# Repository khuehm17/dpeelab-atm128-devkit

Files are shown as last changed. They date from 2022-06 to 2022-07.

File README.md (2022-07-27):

# ATMEGA128 DEVELOPMENT KIT 
## Design by DPEE Lab
## #dpeelab-atm128-devkit
---
## Project description

An open-source AVR ATMega128 Development board KIT design with sample firmware

---
## Features
- 5V/3A Power supply
- ATMega128X compatibility
- USB Type C Serial UART
- JTAG/ISP Debug, programmer header
- Stackable with another module or extension board

---
## Hardware Revision 1.0

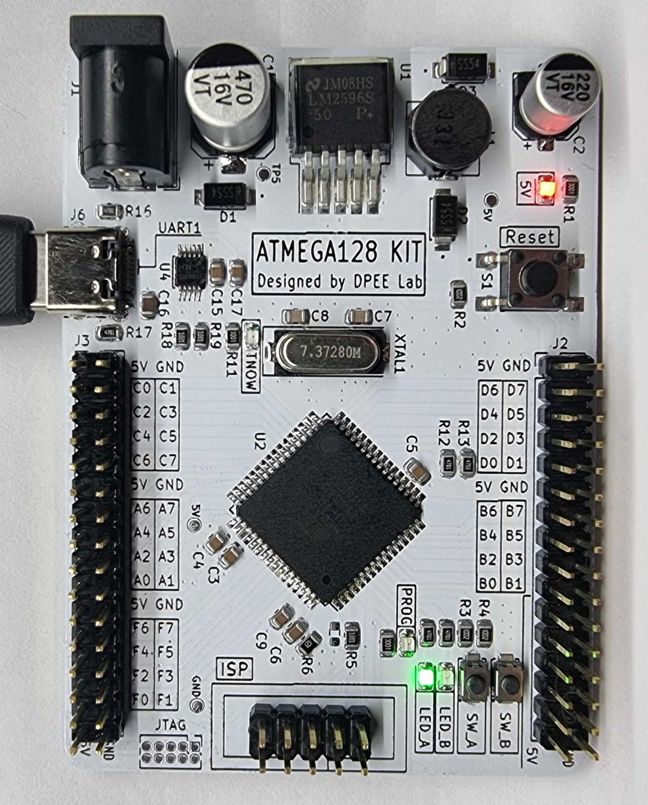
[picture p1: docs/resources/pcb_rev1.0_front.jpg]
MarineGEO circle logo


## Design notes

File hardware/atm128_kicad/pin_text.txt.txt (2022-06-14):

--- J2
5V GND
D6 D7
D4 D5
D2 D3
D0 D1
5V GND
B6 B7
B4 B5
B2 B3
B0 B1
5V GND
--- J3
5V GND
C0 C1
C2 C3
C4 C5
C6 C7
5V GND
A6 A7
A4 A5
A2 A3
A0 A1
5V GND
F6 F7
F4 F5
F2 F3
F0 F1

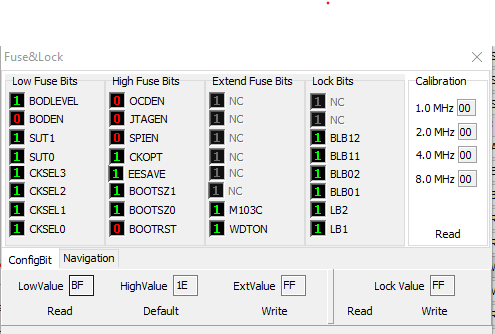
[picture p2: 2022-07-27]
docs/resources/fuse_bits.png

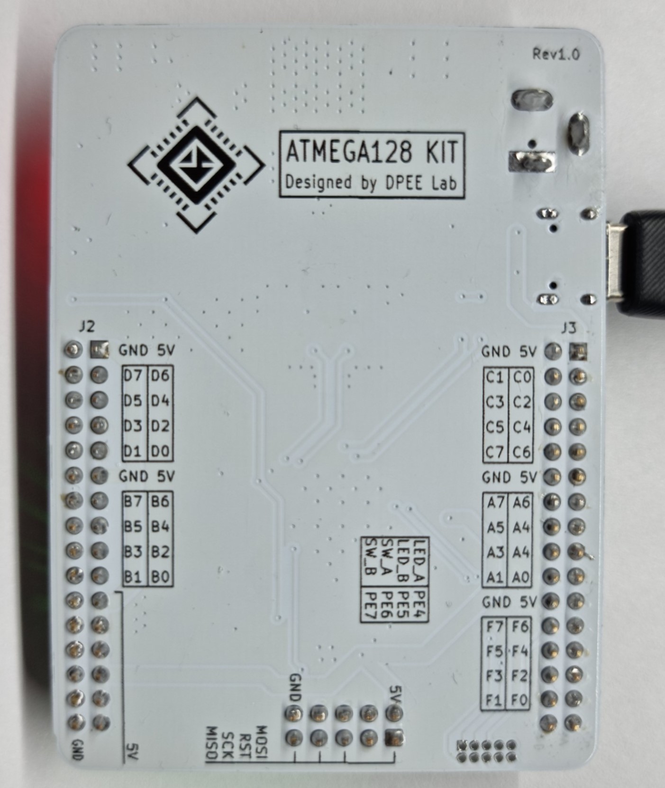
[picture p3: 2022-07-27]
docs/resources/pcb_rev1.0_back.jpg

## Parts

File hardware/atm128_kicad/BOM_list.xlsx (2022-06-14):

Id | Designator | Package | Quantity | Designation | Supplier and ref | Ready | Ordered
1 | J6 | USB_Micro-B_Molex-105017-0001 | 1 | USB_B_Mini | https://www.thegioiic.com/products/cong-usb-micro-b-2-0-dau-cai-5-chan-smd-v1 |  | v
2 | R4,R2,R3 | R_0805_2012Metric | 3 | 10k | https://www.thegioiic.com/products/dien-tro-10-kohm-0805-1 |  | v
3 | TP1,TP2,TP3 | TestPoint_Pad_D1.0mm | 3 | 5V |  | v
4 | R10,R5,R14,R1,R7,R15,R11,R8 | R_0805_2012Metric | 8 | 1k | https://www.thegioiic.com/products/dien-tro-1-kohm-0805-5- | v
5 | R9 | R_0603_1608Metric | 1 | DNP | https://www.thegioiic.com/products/dien-tro-0-ohm-0603-5- |  | v
6 | C6 | C_0805_2012Metric | 1 | C |  |  | v
7 | R13,R12 | R_0805_2012Metric | 2 | 4k7 | https://www.thegioiic.com/products/dien-tro-4-7-kohm-0805-1- |  | v
8 | L1 | IND_B1047AS-331M=P3 | 1 | 330uH | https://www.thegioiic.com/products/cuon-cam-dan-smd-7345-331-330uh-390ma |  | v
9 | D7 | LED_0805_2012Metric | 1 | TX | https://www.thegioiic.com/products/led-xanh-la-0805-dan-smd-trong-suot |  | v
10 | J1 | BarrelJack_GCT_DCJ200-10-A_Horizontal | 1 | Barrel_Jack_Switch_Pin3Ring
11 | C12 | C_0805_2012Metric | 1 | 10nF | https://www.thegioiic.com/products/tu-gom-0805-10nf-50v |  | v
12 | U2 | TQFP-64_14x14mm_P0.8mm | 1 | ATmega128-16A | https://www.thegioiic.com/products/atmega1281-16au |  | v
13 | J3,J2 | PinHeader_2x16_P2.54mm_Vertical | 2 | Conn_02x16_Odd_Even
14 | D4 | LED_0805_2012Metric | 1 | 5V | https://www.thegioiic.com/products/led-xanh-la-0805-dan-smd-trong-suot
15 | XTAL1 | Crystal_SMD_HC49-SD | 1 | 7.3728M | https://www.thegioiic.com/products/thach-anh-7-3728mhz-2-chan-smd-hc49-s |  | v
16 | C13,C9 | C_0805_2012Metric | 2 | 100nF | https://www.thegioiic.com/products/tu-gom-0805-100nf-0-1uf-50v |  | v
17 | U1 | TO-263-5_TabPin3 | 1 | LM2596S-5 | https://www.thegioiic.com/products/lm2596s-5-0-ic-dieu-chinh-giam-ap-5v-3a-to-263-5 |  | v
18 | D6 | LED_0805_2012Metric | 1 | LED_B | https://www.thegioiic.com/products/led-xanh-la-0805-dan-smd-trong-suot
19 | C8,C7 | C_0805_2012Metric | 2 | 22pF | https://www.thegioiic.com/products/tu-gom-0805-22pf-50v |  | v
20 | C4,C5,C3 | C_0805_2012Metric | 3 | 0.1uF | https://www.thegioiic.com/products/tu-gom-0805-100nf-0-1uf-50v
21 | D5 | LED_0805_2012Metric | 1 | LED_A | https://www.thegioiic.com/products/led-xanh-la-0805-dan-smd-trong-suot
22 | Y1 | Crystal_SMD_5032-2Pin_5.0x3.2mm | 1 | Crystal | https://www.thegioiic.com/products/thach-anh-12mhz-5032-2-chan-crystal |  | v
23 | C1 | CP_Elec_8x10.5 | 1 | 470uf | https://www.thegioiic.com/products/tu-nhom-smd-470uf-16v-8x10-5mm |  | v
24 | D1,D3,D2 | DIOM4325X250N | 3 | P4SMA13 | https://www.thegioiic.com/products/ss54-sma |  | v
25 | J5 | PinHeader_2x05_P1.27mm_Vertical | 1 | JTAG
26 | C10,C14,C11 | C_0805_2012Metric | 3 | 1uF | https://www.thegioiic.com/products/tu-gom-0805-1uf-25v |  | v
27 | TP4 | TestPoint_Pad_D1.0mm | 1 | GND
28 | J4 | PinHeader_1x06_P2.54mm_Vertical | 1 | ISP | https://www.thegioiic.com/products/hang-rao-duc-don-2-54mm-40-chan-1-hang-cao-11-2mm-xuyen-lo-loai-tot |  | v
29 | C2 | CP_Elec_6.3x7.7 | 1 | 220uf | https://www.thegioiic.com/products/tu-nhom-smd-220uf-16v-6-3x7-7mm | v
30 | S3 | SW_TL1015AF160QG | 1 | SW_B | https://www.thegioiic.com/products/nut-nhan-3x4mm-cao-2-5mm-2-chan-smd |  | v
31 | D8 | LED_0805_2012Metric | 1 | RX | https://www.thegioiic.com/products/led-xanh-la-0805-dan-smd-trong-suot
32 | S2 | SW_TL1015AF160QG | 1 | SW_A | https://www.thegioiic.com/products/nut-nhan-3x4mm-cao-2-5mm-2-chan-smd |  | v
33 | S1 | SW_4-1437565-9 | 1 | RST | https://www.thegioiic.com/products/nut-nhan-6x6mm-cao-4-3mm-4-chan-smd | v
34 | U3 | SOIC-16_3.9x9.9mm_P1.27mm | 1 | CH340G | https://www.thegioiic.com/products/ch340g |  | v
35 | R6 | R_0805_2012Metric | 1 | 120R | https://www.thegioiic.com/products/dien-tro-120-ohm-0805-5- |  | v

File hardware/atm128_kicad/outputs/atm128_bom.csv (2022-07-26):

Id | Designator | Package | Quantity | Designation | Supplier and ref | Column1 | _1
1 | R4,R2,R3 | R_0805_2012Metric | 3 | 10k
2 | TP1,TP2 | TestPoint_Pad_D1.0mm | 2 | 5V
3 | J4 | IDC-Header_2x05_P2.54mm_Vertical | 1 | ISP
4 | R10,R5,R1,R7,R11,R19,R18,R8 | R_0805_2012Metric | 8 | 1k
5 | R9 | R_0603_1608Metric | 1 | DNP
6 | C6,C17,C4,C9,C5,C3 | C_0805_2012Metric | 6 | 100nF
7 | R13,R12 | R_0805_2012Metric | 2 | 4k7
8 | L1 | IND_B1047AS-331M=P3 | 1 | 330uH
9 | D7 | LED_0805_2012Metric | 1 | PROG
10 | J1 | BarrelJack_GCT_DCJ200-10-A_Horizontal | 1 | Power Jack
11 | U2 | TQFP-64_14x14mm_P0.8mm | 1 | ATmega128-16A
12 | J3,J2 | PinHeader_2x16_P2.54mm_Vertical | 2 | Conn_02x16_Odd_Even
13 | D4 | LED_0805_2012Metric | 1 | 5V
14 | XTAL1 | Crystal_SMD_HC49-SD | 1 | 7.3728M
15 | U1 | TO-263-5_TabPin3 | 1 | LM2596S-5
16 | D6 | LED_0805_2012Metric | 1 | LED_B
17 | C8,C7 | C_0805_2012Metric | 2 | 22pF
18 | D5 | LED_0805_2012Metric | 1 | LED_A
19 | D8 | LED_0805_2012Metric | 1 | TNOW
20 | C1 | CP_Elec_8x10.5 | 1 | 470uf
21 | R16,R17 | R_0805_2012Metric | 2 | 5.1k
22 | D1,D3,D2 | DIOM4325X250N | 3 | P4SMA13
23 | J5 | PinHeader_2x05_P1.27mm_Vertical | 1 | JTAG
24 | TP4 | TestPoint_Pad_D1.0mm | 1 | GND
25 | TP5 | TestPoint_Pad_D1.0mm | 1 | Power In
26 | C2 | CP_Elec_6.3x7.7 | 1 | 220uf
27 | U4 | MSOP-10_3x3mm_P0.5mm | 1 | CH340E
28 | S3 | SW_TL1015AF160QG | 1 | SW_B
29 | C16 | C_0805_2012Metric | 1 | 1uF
30 | C15 | C_0805_2012Metric | 1 | 10nF
31 | S2 | SW_TL1015AF160QG | 1 | SW_A
32 | S1 | SW_4-1437565-9 | 1 | Reset
33 | J6 | USB_C_Receptacle_HRO_TYPE-C-31-M-12 | 1 | USB_C_Receptacle_USB2.0
34 | R6 | R_0805_2012Metric | 1 | 120R

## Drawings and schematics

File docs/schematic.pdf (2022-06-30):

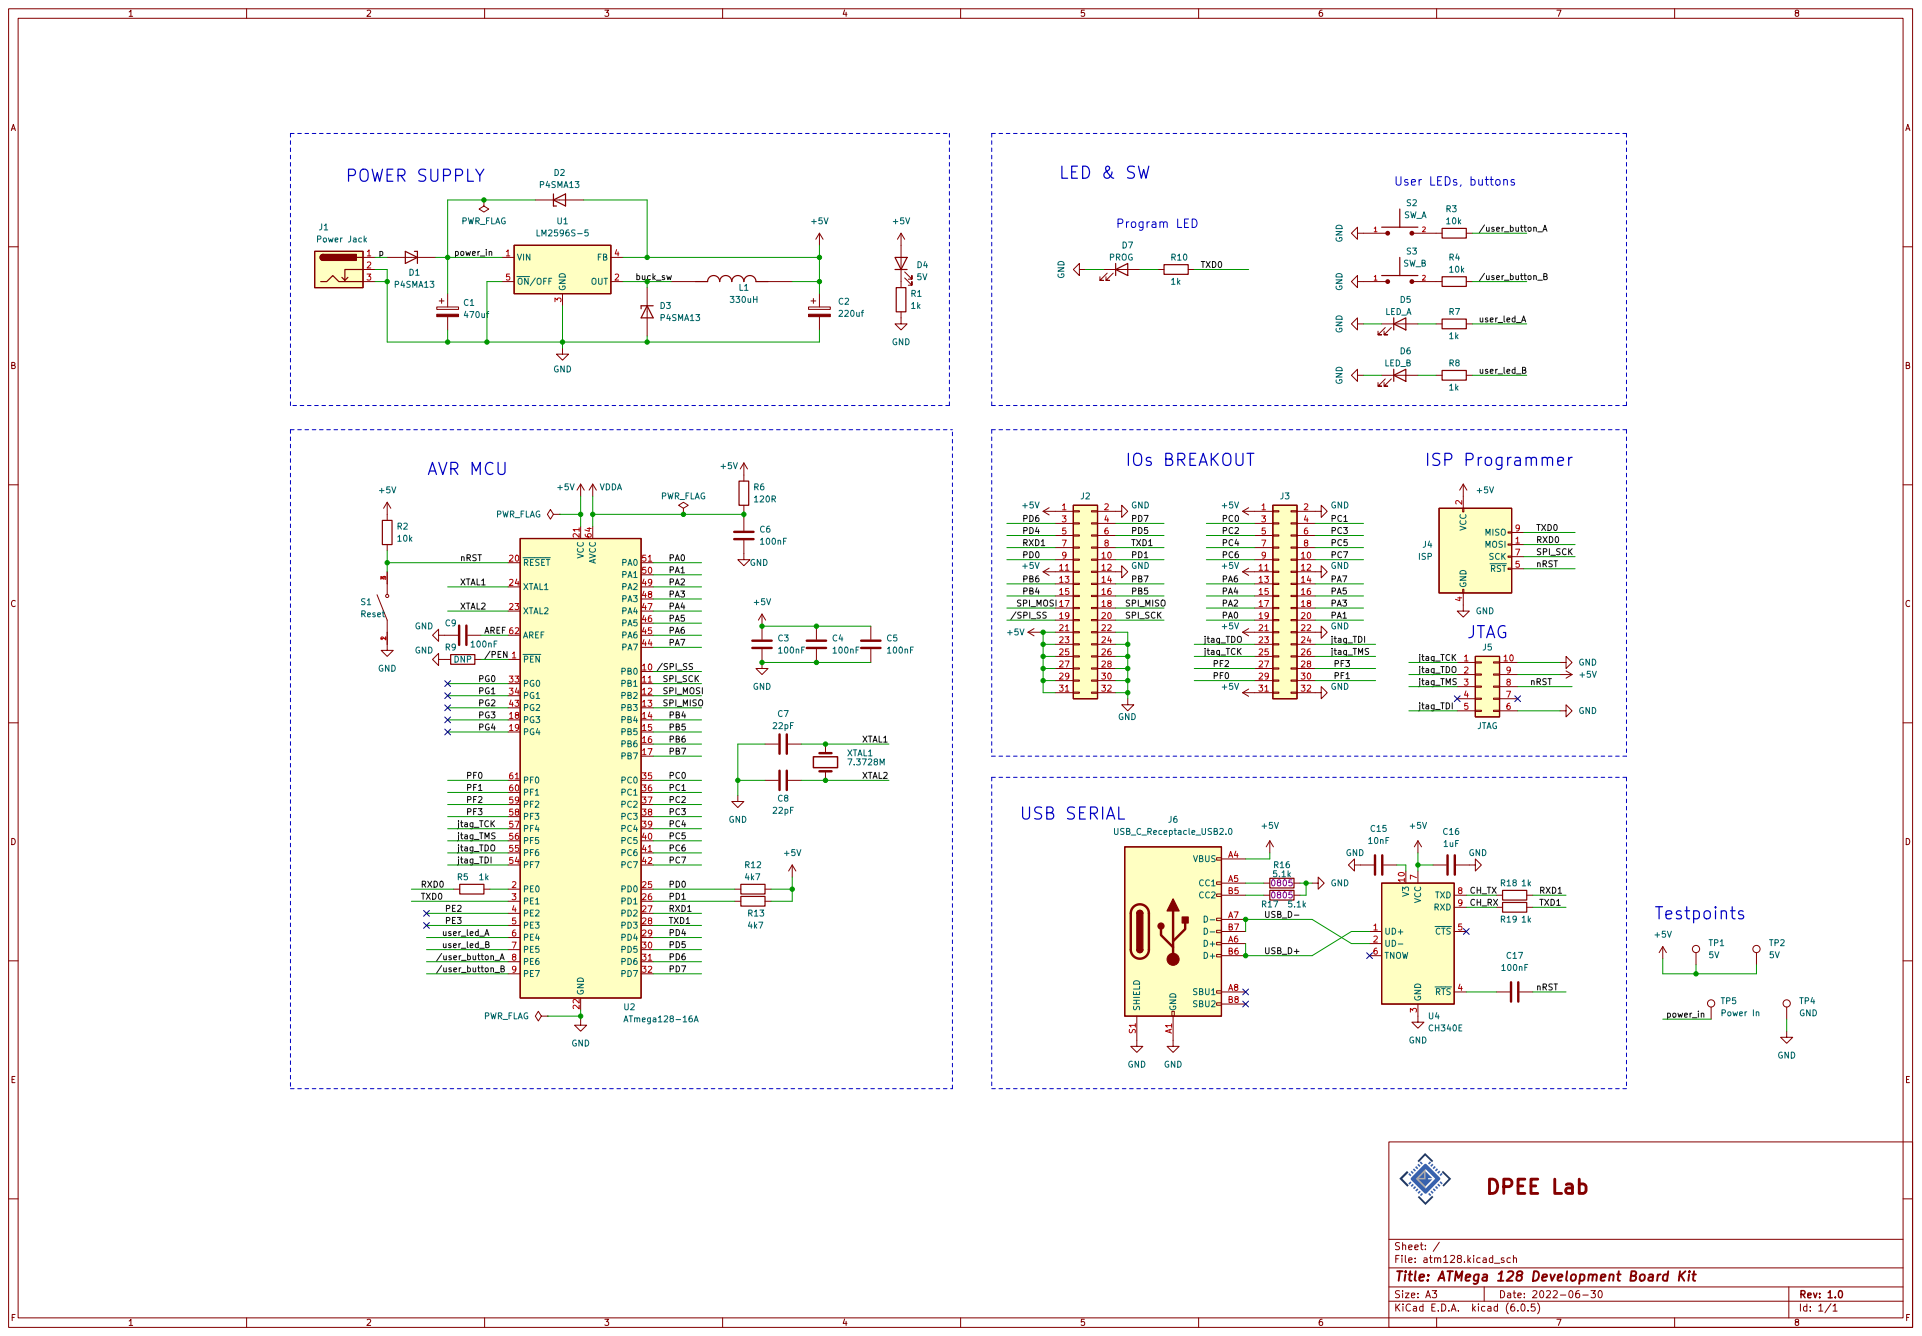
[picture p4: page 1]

25 | 26 | jtag_TCK 25 | 26 jtag_TMS
27 | 28 | 27 | 28
29 | 30 | 29 | 30
31 | 32

3 ~{RTS} 4 ~{CTS} 5 TNOW 6 VCC

Id: 1/1 Title: ATMega 128 Development Board Kit

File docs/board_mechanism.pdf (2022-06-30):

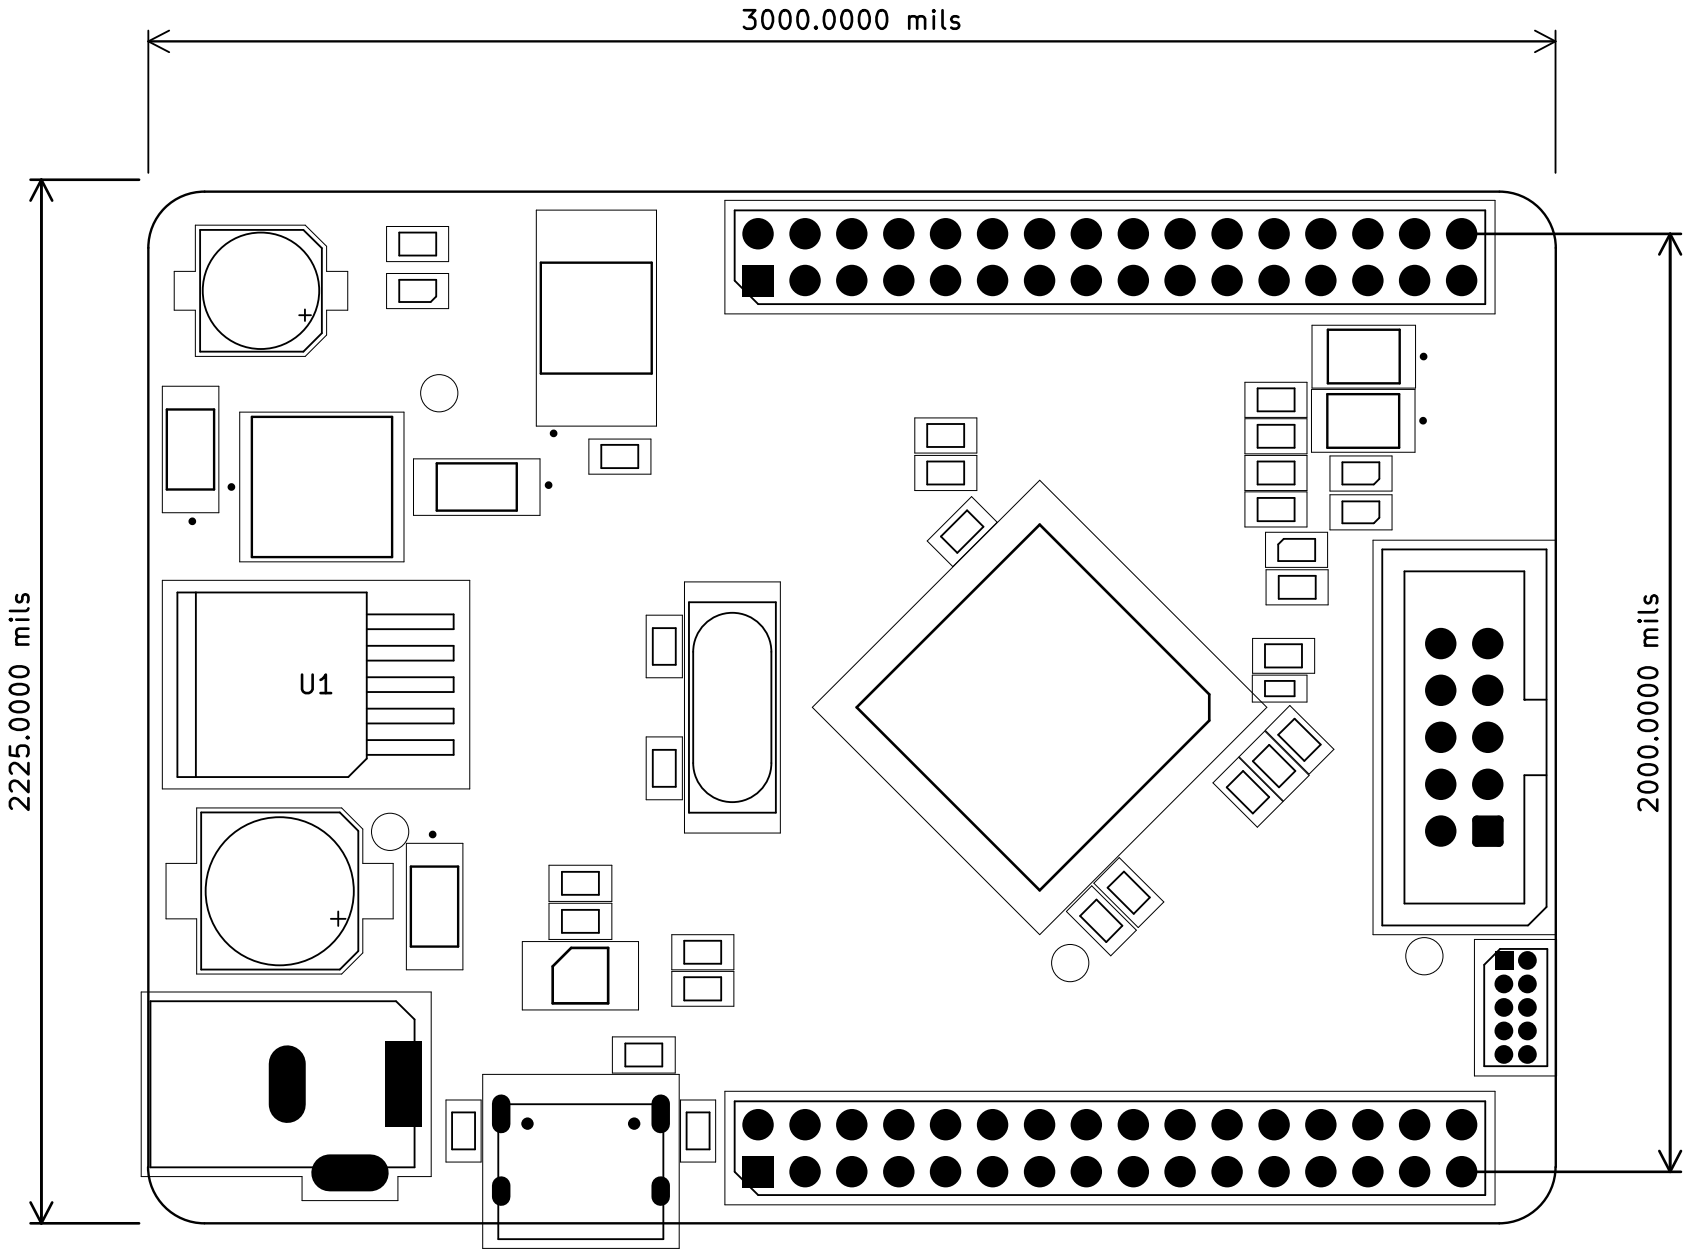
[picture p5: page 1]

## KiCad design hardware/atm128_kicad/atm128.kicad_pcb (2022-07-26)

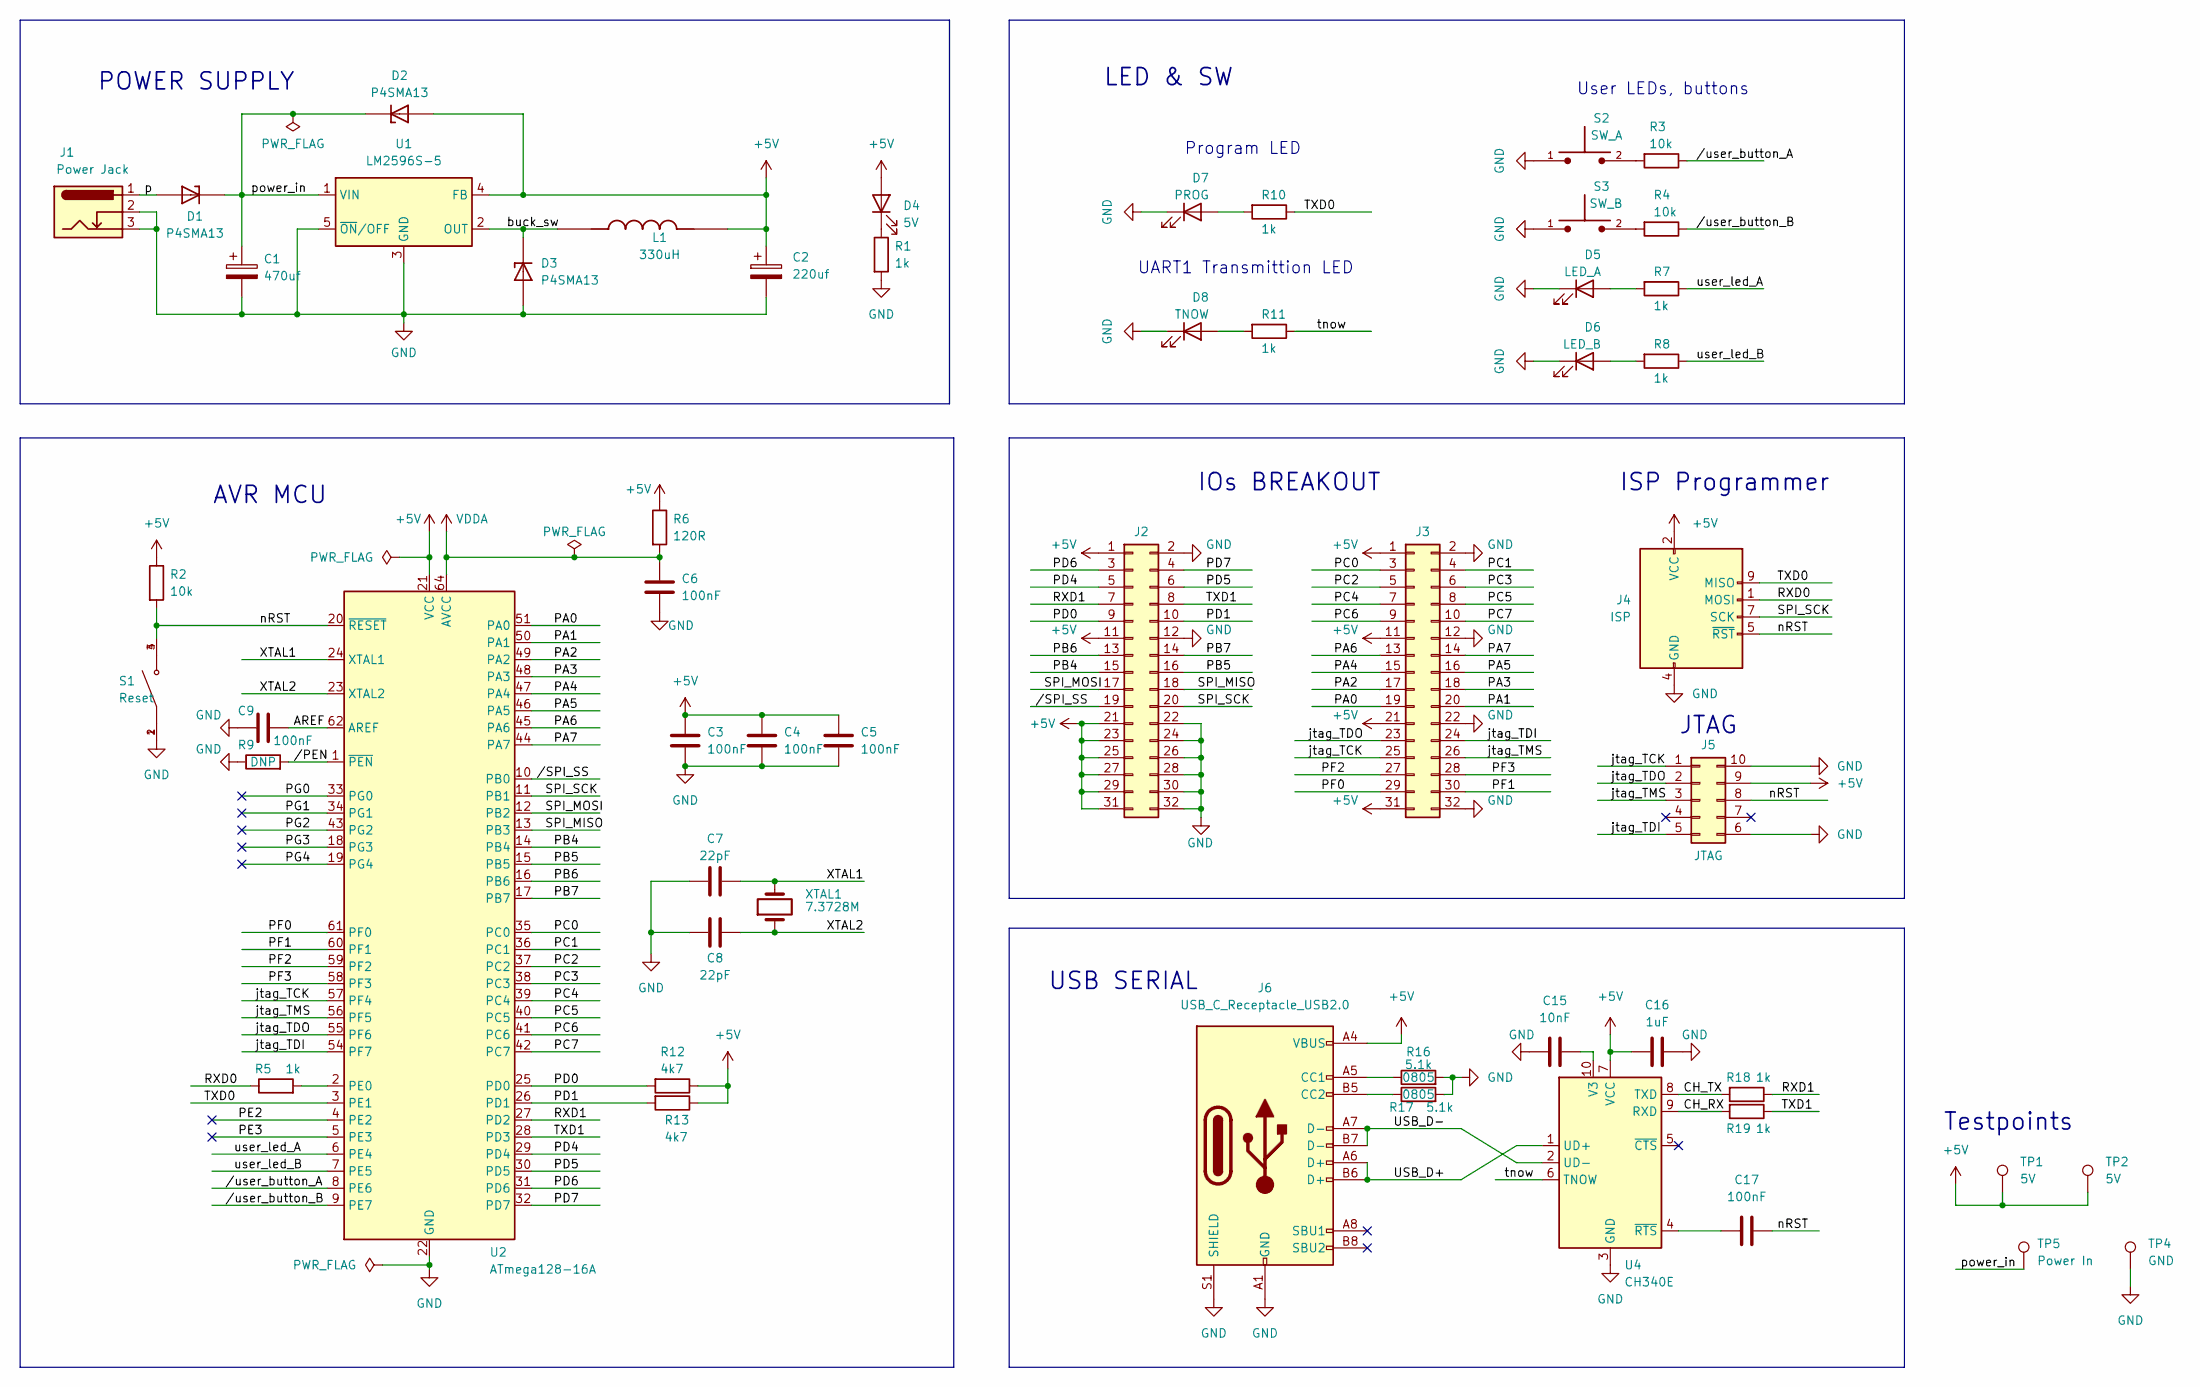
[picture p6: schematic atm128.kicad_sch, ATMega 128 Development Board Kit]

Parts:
C1: 470uf; CP_Elec_8x10.5
C2: 220uf; CP_Elec_6.3x7.7
C3, C4, C5, C6, C9, C17: 100nF; C_0805_2012Metric
C7, C8: 22pF; C_0805_2012Metric
C15: 10nF; C_0805_2012Metric
C16: 1uF; C_0805_2012Metric
D1, D2, D3: P4SMA13; DIOM4325X250N; PARTREV S2102
D4: 5V; LED_0805_2012Metric
D5: LED_A; LED_0805_2012Metric
D6: LED_B; LED_0805_2012Metric
D7: PROG; LED_0805_2012Metric
D8: TNOW; LED_0805_2012Metric
J1: Power Jack; BarrelJack_GCT_DCJ200-10-A_Horizontal
J2, J3: Conn_02x16_Odd_Even; PinHeader_2x16_P2.54mm_Vertical
J4: ISP; IDC-Header_2x05_P2.54mm_Vertical
J5: JTAG; PinHeader_2x05_P1.27mm_Vertical
J6: USB_C_Receptacle_USB2.0; USB_C_Receptacle_HRO_TYPE-C-31-M-12
L1: 330uH; IND_B1047AS-331M=P3; PARTREV N/A
R1, R5, R7, R8, R10, R11, R18, R19: 1k; R_0805_2012Metric
R2, R3, R4: 10k; R_0805_2012Metric
R6: 120R; R_0805_2012Metric
R9: DNP; R_0603_1608Metric
R12, R13: 4k7; R_0805_2012Metric
R16, R17: 5.1k; R_0805_2012Metric
S1: Reset; SW_4-1437565-9
S2: SW_A; SW_TL1015AF160QG; PARTREV F
S3: SW_B; SW_TL1015AF160QG; PARTREV F
TP1, TP2: 5V; TestPoint_Pad_D1.0mm
TP4: GND; TestPoint_Pad_D1.0mm
TP5: Power In; TestPoint_Pad_D1.0mm
U1: LM2596S-5; TO-263-5_TabPin3
U2: ATmega128-16A; TQFP-64_14x14mm_P0.8mm
U4: CH340E; MSOP-10_3x3mm_P0.5mm
XTAL1: 7.3728M; Crystal_SMD_HC49-SD

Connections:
+5V: C2.1, C3.1, C4.1, C5.1, C16.2, D2.A, D4.2 (A), J2.1, J2.11, J2.21, J2.23, J2.25, J2.27, J2.29, J2.31, J3.1, J3.11, J3.21, J3.31, J4.2 (VCC), J5.9, J6.A4 (VBUS), J6.A9 (VBUS), J6.B4 (VBUS), J6.B9 (VBUS), L1.2, R2.1, R6.1, R12.1, R13.1, TP1.1, TP2.1, U1.4 (FB), U2.21 (VCC), U2.52 (VCC), U4.7 (VCC)
/AREF: C9.2, U2.62 (AREF)
/CH_RX: R19.2, U4.9 (RXD)
/CH_TX: R18.2, U4.8 (TXD)
/PA0: J3.19, U2.51 (PA0)
/PA1: J3.20, U2.50 (PA1)
/PA2: J3.17, U2.49 (PA2)
/PA3: J3.18, U2.48 (PA3)
/PA4: J3.15, U2.47 (PA4)
/PA5: J3.16, U2.46 (PA5)
/PA6: J3.13, U2.45 (PA6)
/PA7: J3.14, U2.44 (PA7)
/PB4: J2.15, U2.14 (PB4)
/PB5: J2.16, U2.15 (PB5)
/PB6: J2.13, U2.16 (PB6)
/PB7: J2.14, U2.17 (PB7)
/PC0: J3.3, U2.35 (PC0)
/PC1: J3.4, U2.36 (PC1)
/PC2: J3.5, U2.37 (PC2)
/PC3: J3.6, U2.38 (PC3)
/PC4: J3.7, U2.39 (PC4)
/PC5: J3.8, U2.40 (PC5)
/PC6: J3.9, U2.41 (PC6)
/PC7: J3.10, U2.42 (PC7)
/PD0: J2.9, R12.2, U2.25 (PD0)
/PD1: J2.10, R13.2, U2.26 (PD1)
/PD4: J2.5, U2.29 (PD4)
/PD5: J2.6, U2.30 (PD5)
/PD6: J2.3, U2.31 (PD6)
/PD7: J2.4, U2.32 (PD7)
/PE2: U2.4 (PE2)
/PE3: U2.5 (PE3)
/PF0: J3.29, U2.61 (PF0)
/PF1: J3.30, U2.60 (PF1)
/PF2: J3.27, U2.59 (PF2)
/PF3: J3.28, U2.58 (PF3)
/PG0: U2.33 (PG0)
/PG1: U2.34 (PG1)
/PG2: U2.43 (PG2)
/PG3: U2.18 (PG3)
/PG4: U2.19 (PG4)
/RXD0: J4.1 (MOSI), R5.1
/RXD1: J2.7, R18.1, U2.27 (PD2)
/SPI_MISO: J2.18, U2.13 (PB3)
/SPI_MOSI: J2.17, U2.12 (PB2)
/SPI_SCK: J2.20, J4.7 (SCK), U2.11 (PB1)
/TXD0: J4.9 (MISO), R10.1, U2.3 (PE1)
/TXD1: J2.8, R19.1, U2.28 (PD3)
/USB_D+: J6.A6 (D+), J6.B6 (D+), U4.1 (UD+)
/USB_D-: J6.A7 (D-), J6.B7 (D-), U4.2 (UD-)
/XTAL1: C7.2, U2.24 (XTAL1), XTAL1.2
/XTAL2: C8.2, U2.23 (XTAL2), XTAL1.1
/buck_sw: D3.C, L1.1, U1.2 (OUT)
/jtag_TCK: J3.25, J5.1, U2.57 (PF4)
/jtag_TDI: J3.24, J5.5, U2.54 (PF7)
/jtag_TDO: J3.23, J5.2, U2.55 (PF6)
/jtag_TMS: J3.26, J5.3, U2.56 (PF5)
/nRST: C17.2, J4.5 (~RST), J5.8, R2.2, S1.3, S1.4, U2.20 (~RESET)
/p: D1.A, J1.1
/power_in: C1.1, D1.C, D2.C, TP5.1, U1.1 (VIN)
/tnow: R11.1, U4.6 (TNOW)
/user_led_A: R7.1, U2.6 (PE4)
/user_led_B: R8.1, U2.7 (PE5)
//PEN: R9.2, U2.1 (~PEN)
//SPI_SS: J2.19, U2.10 (PB0)
//user_button_A: R3.1, U2.8 (PE6)
//user_button_B: R4.1, U2.9 (PE7)
GND: C1.2, C2.2, C3.2, C4.2, C5.2, C6.2, C7.1, C8.1, C9.1, C15.1, C16.1, D3.A, D5.1 (K), D6.1 (K), D7.1 (K), D8.1 (K), J1.2, J1.3, J2.2, J2.12, J2.22, J2.24, J2.26, J2.28, J2.30, J2.32, J3.2, J3.12, J3.22, J3.32, J4.4 (GND), J4.6 (GND), J4.8 (GND), J4.10 (GND), J5.6, J5.10, J6.A1 (GND), J6.A12 (GND), J6.B1 (GND), J6.B12 (GND), J6.S1 (SHIELD), R1.2, R9.1, R16.2, R17.2, S1.1, S1.2, S2.1, S3.1, TP4.1, U1.3 (GND), U1.5 (~ON/OFF), U2.22 (GND), U2.53 (GND), U2.63 (GND), U4.3 (GND)
unnamed: C15.2, U4.10 (V3)
unnamed: C17.1, U4.4 (~RTS)
unnamed: D4.1 (K), R1.1
unnamed: D5.2 (A), R7.2
unnamed: D6.2 (A), R8.2
unnamed: D7.2 (A), R10.2
unnamed: D8.2 (A), R11.2
unnamed: J6.A5 (CC1), R16.1
unnamed: J6.B5 (CC2), R17.1
unnamed: R3.2, S2.2
unnamed: R4.2, S3.2
unnamed: R5.2, U2.2 (PE0)
VDDA: C6.1, R6.2, U2.64 (AVCC)

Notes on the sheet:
JTAG
USB SERIAL
User LEDs, buttons
LED & SW
UART1 Transmittion LED
Program LED
ISP Programmer
AVR MCU
POWER SUPPLY
Testpoints
IOs BREAKOUT

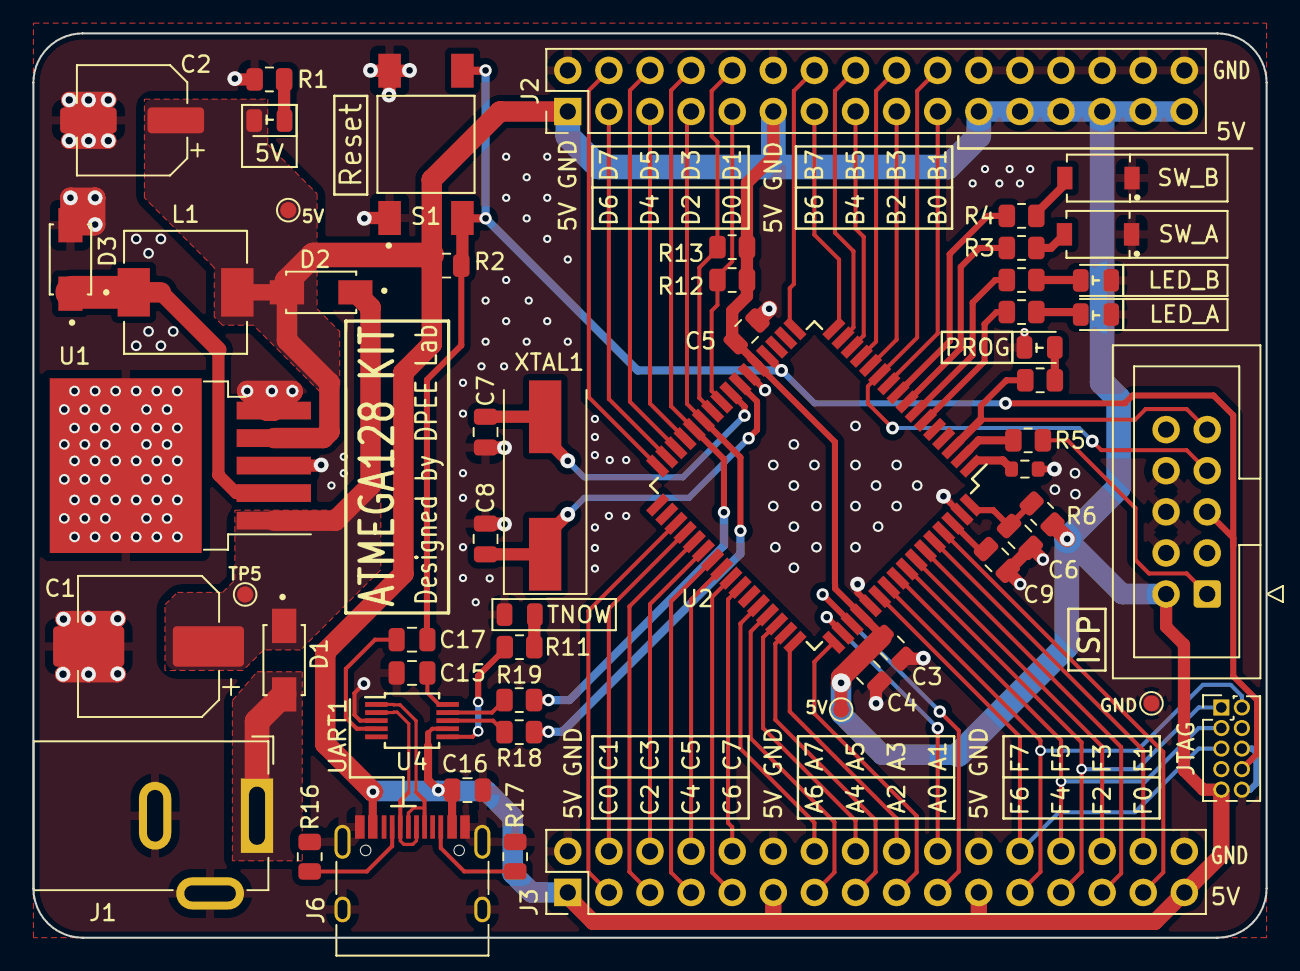
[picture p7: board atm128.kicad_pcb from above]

Board: 2 copper layers, 76.2 x 55.9 mm, 55 parts (0 on the bottom side), 74 nets.

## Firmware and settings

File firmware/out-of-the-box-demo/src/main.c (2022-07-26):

/*
* main.c
*
*  Created on: Mar 7, 2022
*      Author: khueh
*/

/*
*   Include header files
*/
#include <stdint.h>
#include <avr/io.h>
#include <avr/iom128.h>
#include <util/delay.h>
#include <avr/interrupt.h>

#include <util/delay.h>

/*
 *   Define macros
 */
/* Output Port pin LED */
#define PORT_LED_A        PORTE
#define DDR_LED_A         DDRE
#define BIT_LED_A         4

#define PORT_LED_B        PORTE
#define DDR_LED_B         DDRE
#define BIT_LED_B         5

#define PORT_SW_A         PORTE
#define DDR_SW_A          DDRE
#define BIT_SW_A          2

#define LED_BLINK_PERIOD  500

/**************************************************************************
 *                      User-defined Functions Prototype
 **************************************************************************/
void GPIO_Init(void);

/**************************************************************************
 *                           Global Declarations
 **************************************************************************/

/*
*   Main program
*/
int main(void)
{
    GPIO_Init();

    while(1)
    {
        PORT_LED_A |= (1 << BIT_LED_A);
        PORT_LED_B &= ~(1 << BIT_LED_B);
        _delay_ms(LED_BLINK_PERIOD);
        PORT_LED_A &= ~(1 << BIT_LED_A);
        PORT_LED_B |= (1 << BIT_LED_B);
        _delay_ms(LED_BLINK_PERIOD);
    };

    return 0;
}

/**************************************************************************
 *                 User-defined Functions Implementation
 **************************************************************************/
/* Initialize GPIOs */
void GPIO_Init(void)
{
    // Set LED as output pin
    DDR_LED_A |= (1 << BIT_LED_A);
    PORT_LED_A &= ~(1 << BIT_LED_A);

    // Set LED as output pin
    DDR_LED_B |= (1 << BIT_LED_B);
    PORT_LED_B &= ~(1 << BIT_LED_B);
}

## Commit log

2022-06-14 feat[hw]: add hardware PCB design by Kicad prototype Rev0.0
    [BOM_list.xlsx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]
2022-06-22 docs: update schematic and board mechanism rev1.0
2022-06-30 feat: update hw: USB_C, IDC ISP, CH340E
    [atm128.kicad_pcb, atm128.kicad_sch]
2022-06-30 feat: modify J2, J3 space to 2000mils
    [atm128.kicad_pcb]
2022-06-30 feat: update schematic Rev1.0
    [atm128.kicad_pcb, atm128.kicad_sch]
2022-06-30 docs: update board mechanism for Rev1.0
    [atm128.kicad_pcb]
2022-07-19 feat: add TNOW LED, complete review for rev1.0
    [atm128.kicad_pcb, atm128.kicad_sch]
2022-07-19 release: export pcb gerber for fab #rev1.0
    [atm128-B_Cu.gbr, atm128-B_Mask.gbr, atm128-B_Paste.gbr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]
2022-07-26 feat: add BOM for PCB rev1.0
    [atm128.kicad_pcb, atm128_bom.csv]
